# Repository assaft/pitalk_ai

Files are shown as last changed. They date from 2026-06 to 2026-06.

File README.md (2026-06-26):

# Introduction
This MD idescribes the creation of a device for recording, sending, receiving and playing vocal messages. 

## Device Goal
Enable easy voice messaging between kids. One click to start/end recording, one click to play an incoming. 

## Device Components
* Touch screen
* Microphone
* Speaker
* Amplifier
* System on chip - raspberry pi.
* Button with light
* PCB board, header cables, enclosure 

## Typical Use Case
Using the touch screen, user A can initiate a recording of a message to a particular pre-configured friend - user B. The microphone is used for the recording and a file is saved. Once user A presses to finish the recording, the file will be sent over the internet (using a Wifi connection), and reach the device of the recipient - user B. User B's device screen will show that there is an incoming message that hasn't been heard. Once user B presses on the screen to play it, the amplifier and speaker will be used to play it. 

# Requirements

## Functional Requirements
* A user can record a new message and send it to one of his/her friends. 
* A user can browse old messages he/she received and listen to them.
* A user can have a custom different list of friends - each user a different list 
* The list of friends per user should be editable.

## System Requirements
* The device should support reboot, shut down, turn on
* The device should have a Wifi access point mode so smartphones can connect to itto configure the Wifi network.

## Package Engineering Requirements
* The device should be packaged in a compact box
* The device should only have one external connection for power
* The screen, speaker, microphone and button should be front facing.
* The micro USB power should be side-facing.
* The comopnents should be mounted to the top or sides of the box, not to the bottom.
* The bottom should be openable using screws, giving access to all components inside.
* The raspberry pi should be attached on one of the sides to allow easy access to the screen, speaker, microphone and button.
* A custom PCB board should be used to simplify connectivity and maintenance
* The PCB should connect to the Raspberry Pi GPIO interface using a
  2×20 male pin header.

## PCB Board requirements
* The board should not include the amplifier - it should include a female socket for the amplifier to be connected to it using a male header that was soldered to it. 
* The board should not include the microphone because the microphone is attached to the front of the device. The microphone will have pin header soldered to it.
* there should be board connectors on the pcb for connecting it to the microphone, speaker, button and screen; the screen connector should be keyed/locking.

# Components

## Models
1. Controller: Raspberry Pi Zero 2W
2. Screen: Waveshare 2 inch Capacitive Touch Display Module (ST7789T3, CST816D)
3. Speaker: Gikfun 2 inch 4Ohm 3W Full Range Audio Speaker Stereo Woofer Loudspeaker
4. Amplifier: Max98357 I2S 3W Class D Amplifier
5. Microphone: INMP441 Omnidirectional Microphone attached over a Perfboard PCB of 2cm x 2cm
7. Button: momentary push button with led light

## Dimensions

| Component | Length | Width | Depth / Thickness | Notes |
|---|---|---|---|---|
| Raspberry Pi Zero 2W | 65 mm | 30 mm | ~5 mm | Board only; add ~2 mm for protruding micro-SD card |
| Waveshare 2" Capacitive Touch LCD (ST7789T3 / CST816D) | 58.8 mm | 37.1 mm | ~4 mm | PCB size; active display area is 40.8 × 30.6 mm |
| Gikfun 2" 4Ω 3W Speaker | 52.6 mm | 52.6 mm | 30 mm | Square frame |
| MAX98357 I2S Class-D Amplifier (breakout) | 19.4 mm | 17.8 mm | 3 mm | Adafruit-style breakout board |
| INMP441 Microphone (on 20 × 20 mm perfboard) | 20 mm | 20 mm | ~11 mm | Perfboard size per design spec; sensor itself is 4.7 × 3.8 × 1 mm |
| Momentary Push Button with LED | Ø 16–22 mm | — | ~39 mm | Circular; diameter depends on selected model (common: 16 mm or 22 mm panel cutout) |

# Box Arrangement

Two candidate front-face layouts. Scale: 1 char ≈ 5 mm.

## Layout 1 — Portrait (80 × 155 mm)

Screen on top, speaker in the middle, mic and button at the bottom.

```
╔══════════════════╗
║                  ║
║  ┌────────────┐  ║
║  │            │  ║
║  │   SCREEN   │  ║  58.8 × 37.1 mm
║  │            │  ║
║  └────────────┘  ║
║                  ║
║   ┌──────────┐   ║
║   │ ·  ·  ·  │   ║
║   │  ·  ·  · │   ║  52.6 × 52.6 mm
║   │ ·  ·  ·  │   ║
║   │  ·  ·  · │   ║
║   └──────────┘   ║
║                  ║
║   ◎         ◉    ║
║   mic       btn  ║
╚══════════════════╝
     80 × 155 mm
```

USB-C on the right side.

## Layout 4 — Landscape (150 × 80 mm)

Speaker on the left, screen on the right, mic and button below the screen.

```
╔══════════════════════════════════════╗
║                                      ║
║  ┌────────────┐  ┌────────────┐      ║
║  │ ·  ·  ·  · │  │            │      ║
║  │  ·  ·  ·   │  │   SCREEN   │      ║  58.8 × 37.1 mm
║  │ ·  ·  ·  · │  │            │      ║
║  │  ·  ·  ·   │  └────────────┘      ║
║  └────────────┘       ◎    ◉         ║
║                      mic   btn       ║
╚══════════════════════════════════════╝
  52.6 × 52.6 mm          150 × 80 mm
```

USB-C on the bottom edge (side of box). Button centered below screen, mic to its left.

## Internal Layout

### View from bottom

### View from the side

# PCB Design

Board: **76 mm × 58 mm**, four-layer, 1.6 mm FR4:

1. `F.Cu` — connector escapes and signals
2. `In1.Cu` — continuous ground plane
3. `In2.Cu` — secondary signal routing
4. `B.Cu` — signals and power

The authoritative wiring specification is [`pcb/pcb.md`](pcb/pcb.md). The
KiCad board is [`pcb/kicad/pitalk.kicad_pcb`](pcb/kicad/pitalk.kicad_pcb).
The matching schematic is
[`pcb/kicad/pitalk.kicad_sch`](pcb/kicad/pitalk.kicad_sch).

Regenerate it with:

```sh
.venv/bin/python pcb/kicad/build.py
.venv/bin/python pcb/kicad/build_schematic.py
```

## Connectors

| Ref | Footprint | Function |
|-----|---|---|
| J1 | 2×20 2.54 mm male pin header | Raspberry Pi Zero 2W GPIO |
| J2 | JST GH SM15B 1.25 mm 1×15 male side-entry header | Waveshare 2" touch display |
| J3 | 1×7 2.54 mm female socket | MAX98357A amplifier module |
| J4, J5 | 1×3 2.54 mm male headers | INMP441 microphone |
| J6 | 1×4 2.54 mm male header | Momentary button + LED |

## GPIO Assignments (Raspberry Pi Zero 2W)

| Pin | GPIO | Net | Description |
|-----|---|-----|---|
| 1, 17 | 3V3 | +3V3 | Power |
| 2, 4 | 5V | +5V | Power (amp) |
| 3 | GPIO2 | I2C_SDA | Touch screen SDA |
| 5 | GPIO3 | I2C_SCL | Touch screen SCL |
| 7 | GPIO4 | TOUCH_INT | Touch interrupt |
| 12 | GPIO18 | I2S_BCLK | I2S bit clock (amp + mic) |
| 13 | GPIO27 | DISP_RST | Display reset |
| 15 | GPIO22 | BTN_SW | Button input |
| 19 | GPIO10 | SPI_MOSI | Display data |
| 22 | GPIO25 | DISP_DC | Display data/command |
| 23 | GPIO11 | SPI_SCLK | Display clock |
| 24 | GPIO8 | SPI_CE0 | Display chip select |
| 32 | GPIO12 | DISP_BL | Backlight PWM |
| 33 | GPIO13 | GPIO13 | LED drive (→ R1 → BTN_LED) |
| 35 | GPIO19 | I2S_LRCLK | I2S LR clock (amp + mic) |
| 38 | GPIO20 | I2S_DIN | I2S data from mic → RPi |
| 40 | GPIO21 | I2S_DOUT | I2S data RPi → amp |

## Passives

| Ref | Value | Purpose |
|-----|---|---|
| R1 | 330 Ω 0402 | BTN_LED current limiter (GPIO13 → LED) |
| C1 | 100 nF 0402 | +3V3 decoupling |
| C2 | 100 nF 0402 | +5V decoupling |

# Software code

# Todos 
* ~~Adding the component dimensions - width, height, depth - see section above.~~
* ~~Creating the box arrangment for organizing the components in a box - see section above.~~
* ~~Create a PCB board to simplify connections and maintenance - see section above.~~
* Writing the software for implementing the service.

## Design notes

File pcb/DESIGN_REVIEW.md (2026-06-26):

# PiTalk PCB — Independent Verification Report

**Reviewer pass date:** 2026-06-27 (third pass — re-verification after the
fabrication-output regeneration, commit `b4b90ed`; second pass covered the
silkscreen-label update, commit `3b99e36`)
**Scope:** schematic, netlist, PCB, DRC/ERC, layout, datasheet pinouts,
connector silkscreen.
**Sources reviewed:** `pcb.md`, `kicad/pitalk.kicad_sch`, `kicad/pitalk.kicad_pcb`,
`kicad/pitalk.net.xml`, `kicad/erc.json`, `kicad/drc.json`, `kicad/build.py`,
`kicad/board-statistics.rpt`, `kicad/PRE_MANUFACTURING_VALIDATION.md`.

## What changed since the previous pass — and whether the verdict moves

The only board change since the first review (`720910e`) was **adding 20
assembly-facing pin labels to the front silkscreen** (`3b99e36`). I confirmed
this directly:

- **The schematic and netlist are byte-for-byte unchanged** (`git diff 720910e
  HEAD -- pitalk.kicad_sch pitalk.net.xml` is empty). Every electrical finding
  from the first pass therefore still holds without re-litigation — the
  I2S/backlight pin-conflict resolution, C1 polarity, no double-driven pins, and
  the NC list are all still correct.
- **The 20 new silkscreen labels are all correct** (§4 below).
- **The fabrication-output staleness (Finding #5) is now resolved** by commit
  `b4b90ed`. All of `kicad/fabrication/` plus `board-statistics.rpt`/`drc.json`
  were regenerated (dated 2026-06-27 01:26–01:27) from the current board, and
  re-verified this pass (§5 below).

**Net answer to "is the result any different than before?"** The electrical
verdict is unchanged (still sound). The board is now better documented for
assembly (correct pin labels) **and** the fabrication outputs are now current
and consistent with the source — Finding #5 is closed.

## Methodology

The intended netlist was reconstructed by hand from `pcb.md` and compared
node-by-node against the KiCad-exported netlist (`pitalk.net.xml`). Footprints,
the PCB stackup/zones/outline, and the automated ERC/DRC/parity reports were
then independently cross-checked. No KiCad, Python, or PCB design files were
modified during this review. Two documentation findings (#1, #3 below) were
corrected in `pcb.md`.

---

## 1. Electrical netlist — cross-checked against `pcb.md` ✅

Every signal net matches the spec. All 21 functional nets verified:

| Net | Pi pin(s) | Accessory | Verdict |
|---|---|---|---|
| SPI_MOSI/MISO/SCLK | 19/21/23 | J2 5/4/6 | ✅ |
| LCD_CS/DC/RST | 24/22/13 | J2 8/9/10 | ✅ |
| LCD_BL | 32 (BCM12) | J2 11 | ✅ remap from BCM18 honored |
| TP_SDA/SCL/INT/RST | 3/5/7/11 | J2 12/13/14/15 | ✅ |
| I2S_BCLK | 12 (BCM18) | J3 2 + J5 3 | ✅ shared amp+mic |
| I2S_LRCLK | 35 (BCM19) | J3 1 + J5 2 | ✅ shared amp+mic |
| AMP_DIN | 40 (DOUT) | J3 3 | ✅ |
| MIC_SD | 38 (DIN) | J4 1 | ✅ full-duplex I2S correct |
| BTN_SW / LED_A | 15 / 33→R1→J6 3 | J6 1 | ✅ 330 Ω in series |
| +3V3 | 1, 17 | J2 1, J4 2 | ✅ |
| +5V | 2 | J3 7, C1+ | ✅ |
| GND | 6,9,14,20,25,30,34,39 | all module grounds, C1− | ✅ |

- **I2S bus conflict avoidance is correct.** BCM18 is freed for the I2S bit
  clock and the backlight is genuinely moved to BCM12 (pin 32) in the netlist —
  the most error-prone part of this design is done right.
- **C1 polarity correct:** pin 1 (+) → +5V, pin 2 (−) → GND.
- **No double-driven pins / no shorts:** every pad appears in exactly one net.
- No-connects match spec: J2.2, J2.7 (module 3V3-out, SD_CS) and J3.4, J3.5
  (GAIN, SD) are NC.

## 2. Automated checks — independently confirmed ✅

- **ERC:** 0 violations. All global labels have a matching partner (each named
  net verified to have ≥2 nodes — no orphan/typo labels).
- **DRC:** 0 violations, 0 unconnected items, **0 schematic/PCB parity issues** —
  the board matches the schematic.
- Min clearance 0.385 mm, min track 0.25 mm, min drill 0.30 mm — all
  comfortably manufacturable.

## 3. Physical / layout — confirmed from the PCB file ✅

- **76 × 58 mm** outline confirmed (Edge.Cuts forms a clean closed rectangle
  0,0 → 76,58).
- **4-layer stack** `F.Cu / In1.Cu (power) / In2.Cu (signal) / B.Cu`, 1.6 mm.
- **In1.Cu is a single continuous GND pour** (one zone, filled, spanning the
  full board with thermal reliefs and mounting-hole keepouts) — no split planes.
  Signals route on F/In2/B (98/34/32 segments). Proper reference plane.
- 4× 3.2 mm NPTH mounting holes present.
- Footprints all match the spec: J2 = side-entry SMD JST GH SM15B; J3 =
  **female** PinSocket 1×07 (matches "socket" requirement); mic on two 1×03
  headers; pad/drill counts reconcile (61 THT + 17 SMD/J2 + 4 NPTH).
- **Outline/stackup/plane re-confirmed on the current file:** Edge.Cuts bbox is
  exactly 0,0 → 76,58; copper stack is `F.Cu / In1.Cu / In2.Cu / B.Cu`; the
  single zone is `(net "GND") (layer "In1.Cu")`. Routing was re-generated by
  `build.py` (now 86/34/32 segments on F/In2/B vs 98/34/32 before) but
  connectivity is intact — see §2 and Finding #5.

## 4. Connector silkscreen labels — independently verified ✅

The 20 new `F.SilkS` text items were extracted from the PCB and each was matched
to the nearest pad and that pad's net. **All 20 are correct in both name and
placement:**

| Connector | Labels (pin order) | Maps to net | Verdict |
|---|---|---|---|
| J4 mic (vertical 1×3) | SD / 3V3 / GND | MIC_SD / +3V3 / GND | ✅ y-aligned, text to the right |
| J5 mic (vertical 1×3) | GND / LRC / BCLK | GND / I2S_LRCLK / I2S_BCLK | ✅ y-aligned |
| J6 button (horizontal 1×4) | SW / GND / LED / GND | BTN_SW / GND / LED_A / GND | ✅ x-aligned, vertical text below |
| J3 amp socket (1×7) | LRC / BCLK / DIN / NC / NC / GND / 5V | I2S_LRCLK / I2S_BCLK / AMP_DIN / NC / NC / GND / +5V | ✅ y-aligned, text to the left |
| J1 Pi header | PIN1, "1=3V3 2=5V", "39=GND 40=DIN" | orientation + high-risk endpoints | ✅ ends labelled correctly |

- All labels are on **F.SilkS** (top/assembly side, where every connector lives)
  — correct, none mirrored onto the back.
- The labels sit clear of the board edge and clear of pads — consistent with
  **DRC reporting 0 silkscreen violations** (no silk-over-pad / silk-clipped).
- Minor cosmetic note only (no action required): J5.1's *module* function is
  `L/R` (the channel-select pin), but it is silkscreened **`GND`** because the
  board ties it to ground. That is electrically accurate; just be aware the
  module's own pin marking there reads `L/R`, not `GND`, when orienting the part.

## 5. Fabrication outputs — regenerated and re-verified ✅

After Finding #5 was raised, commit `b4b90ed` regenerated the full output set.
Independently confirmed against the current board:

- **All `kicad/fabrication/` files re-dated 2026-06-27 01:26**, plus
  `drc.json` (01:27) and `board-statistics.rpt` (01:27) — no longer stale.
- **In1.Cu GND plane is filled in the gerber** (`pitalk-In1_Cu.g1` contains a
  closed `G36…G37` copper region, ~92 kB). Even though the saved
  `.kicad_pcb` still caches the zone unfilled (`filled_polygon` = 0), KiCad
  fills zones on plot, so the *exported* plane is correct and complete — the
  load-bearing GND pour reaches the through-hole pads as required.
- **New silkscreen labels are in the gerber:** `pitalk-F_Silkscreen.gto` grew
  16 kB → 47 kB; `B_Silkscreen` remains ~empty, confirming all 20 labels are
  front-side only (not mirrored to the back).
- **Job/spec consistent:** `pitalk-job.gbrjob` is KiCad/Pcbnew, dated
  2026-06-27 01:26, 76.15 × 58.15 mm (board + plot margin), 4-layer, 1.6 mm,
  ENIG.
- **Counts reconcile with the design:** statistics report 76 × 58 mm, 61 THT +
  17 SMD + 4 NPTH pads; DRC re-run is clean (0 violations, 0 unconnected,
  0 parity).
- `pitalk.ipc` is now a full **IPC-2581 rev C** export (all layers + BOM/AVL),
  which is why it grew from ~7 kB to ~720 kB — a richer interchange format, not
  a defect.

**Residual (latent, low-risk):** the editable `.kicad_pcb` still saves the zone
unfilled because `build.py`/`kiutils` writes only the zone outline. The
committed gerbers are correct, but if anyone re-plots **from the GUI** they
should *Fill All Zones* (`B`) first; a `kicad-cli`/`build.py` re-export fills
automatically.

---

## Findings

**🟢 1 — RESOLVED — Doc/design mismatch on GND pins 20 & 30.**
The schematic ties **all 8** Pi ground pins (6, 9, 14, 20, 25, 30, 34, 39) to
GND, while `pcb.md` previously listed pins 20 and 30 as "not connected." The
schematic's choice is electrically *better* (more ground returns). **Fixed in
`pcb.md`:** pins 20 and 30 are now shown as GND rows in the full-wiring table,
removed from the "Unused header pins" list, and a note clarifies that all eight
Pi ground pins tie to the board GND plane. Design unchanged.

**🟢 2 — RESOLVED (module-confirmed) — Amplifier `GAIN`/`SD` defaults.**
J3.4 (GAIN) and J3.5 (SD) are left NC, relying on the breakout's onboard
resistors. The module's **back-side silkscreen** (now captured in
`images/max98357a-gain-sd-defaults.jpg` and documented in the Amplifier section)
explicitly states its as-shipped defaults: **"Default 9db Gain & (L+R)/2 out"**,
`MAX98357A I2S Mono Amp.`, `Vin: 2.5-5.5V`, `4-8Ω 3W`. This confirms the board
actively pulls `SD` to an *enabled* state in (L+R)/2 mono and leaves `GAIN`
floating for +9 dB — so leaving both pins unconnected on the carrier is correct
and the amp powers up enabled. **Residual check (assembly-time only):** confirm
the unit actually received is the pictured module and not a bare clone lacking
the `SD` pull; the 5 V VIN is within the printed 2.5–5.5 V range and the 4 Ω
speaker is within the printed 4–8 Ω range.

**🟢 3 — RESOLVED — Speaker wording inconsistency.**
The Speaker section previously said the speaker connects "via a 2-pin board
connector," contradicting the PCB Board section ("not a PCB connector"). The
schematic/PCB correctly have **no** speaker connector. **Fixed in `pcb.md`:** the
Speaker section now states the speaker wires directly to the amplifier module's
`OUT+`/`OUT-` terminals and is not a carrier-PCB connector. Design unchanged.

**🟢 4 — No action needed — No external I2C pull-ups / no 3V3 bulk cap.**
Acceptable: the Pi has fixed 1.8 kΩ pull-ups on BCM2/3, and the accessory
modules carry their own local decoupling. Noted for completeness.

**🟢 5 — RESOLVED — GND pour fill & stale fab outputs.**
*Raised on the second pass:* the silkscreen rebuild left the In1.Cu GND pour
saved **unfilled** and the committed `fabrication/` gerbers were **stale**
(Jun 24, pre-label). This mattered because the GND pour is **load-bearing** —
there are **zero GND stitching vias**, so through-hole GND pads depend on the
pour reaching them (plus 35 surface GND segments).

*Resolved by commit `b4b90ed`:* the entire output set was regenerated from the
current board and re-verified (§5 above) — the In1.Cu gerber carries a filled
copper region, `F_Silkscreen` now includes the 20 labels, and DRC/statistics
are current and clean. **Latent caveat retained:** the editable `.kicad_pcb`
still saves the zone unfilled, so a *GUI* re-plot needs *Fill All Zones* (`B`)
first; CLI/`build.py` exports fill automatically.

## Remaining manufacturing gates (cannot be closed from CAD)

Concur with `PRE_MANUFACTURING_VALIDATION.md`. Load-bearing items:

- **Mate/orientation of J1 (2×20) and J2 (15-pin JST GH) cables** — verify pin-1
  and that neither can seat reversed.
- **Physical fit** of the exact INMP441 and MAX98357A modules over a 1:1
  printout.
- **C1 voltage rating** ≥ 6.3 V (10 V preferred); confirm polarity at assembly.
- **Supply budget** for amplifier peaks (~650 mA) to avoid Pi undervoltage.
- **Fab DFM** — map to the chosen vendor's 1.6 mm 4-layer stack (no controlled
  impedance required).
- First-article **continuity / rail-short / functional** bring-up.

## Verdict

**The electrical design is sound and internally consistent — netlist, ERC, DRC,
and schematic↔PCB parity all pass independent verification, and the
I2S/backlight pin-conflict resolution (the trickiest part) is correct.** The
schematic and netlist are unchanged from the first pass, so that verdict carries
over directly. The new connector silkscreen (20 labels) is **fully correct** in
name, net, side, and placement, and improves assembly safety.

**Finding #5 (raised last pass) is now closed:** the fabrication outputs were
regenerated from the current board and independently re-verified — the In1.Cu
gerber carries a filled GND plane, the new silkscreen labels are in
`F_Silkscreen`, and DRC/statistics are current and clean. The only remaining
items are the physical mating/fit gates (cable orientation, module footprints,
C1 rating, supply budget, fab DFM, first-article bring-up) — none of which can
be closed from CAD files alone — and a latent reminder to *Fill All Zones*
before any **manual GUI** gerber re-plot. The design and its fabrication set are
suitable for prototype fabrication.

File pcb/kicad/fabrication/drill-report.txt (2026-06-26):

Drill report for pitalk.kicad_pcb
Created on 2026-06-27T01:26:01

Copper Layer Stackup:
    =============================================================
    L1 :  F.Cu                      front
    L2 :  In1.Cu                    in1
    L3 :  In2.Cu                    in2
    L4 :  B.Cu                      back

Drill file 'pitalk-PTH.drl' contains
    plated through holes:
    =============================================================
    T1  0.300mm  0.0118"  (14 holes))
    T2  0.800mm  0.0315"  (4 holes))
    T3  1.000mm  0.0394"  (57 holes))

    Total plated holes count 75

Drill file 'pitalk-NPTH.drl' contains
    unplated through holes:
    =============================================================
    T1  3.200mm  0.1260"  (4 holes))

    Total unplated holes count 4

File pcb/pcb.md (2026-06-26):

# PiTalk PCB — Pin Connections

This document defines the electrical pin mapping for the PiTalk carrier PCB,
designed from scratch around the **Raspberry Pi Zero 2W** 40-pin header.

Each accessory gets its own section with a pin-mapping table. Columns:

| Column | Meaning |
|---|---|
| `pi_pin` | Physical pin number on the Pi 40-pin header (1–40) |
| `pi_bcm` | Broadcom GPIO number (BCMxx), or the power rail name for power/ground pins |
| `accessory_pin` | Signal/function on the accessory side (e.g. `gnd`, `v3.3`, `clock`) |

> Buses are shared where the hardware requires it: SPI0 drives the display,
> I2C1 drives the touch controller, and the I2S/PCM bus is shared by the
> amplifier (output) and microphone (input).

---

## Raspberry Pi Zero 2W — 40-pin header reference

For convenience, the full header pinout this design draws from:

| pi_pin | pi_bcm | pi_pin | pi_bcm |
|---:|---|---:|---|
| 1  | 3V3 | 2  | 5V |
| 3  | BCM2 (SDA1)| 4  | 5V |
| 5  | BCM3 (SCL1)| 6  | GND |
| 7  | BCM4 | 8  | BCM14 (TXD) |
| 9  | GND | 10 | BCM15 (RXD) |
| 11 | BCM17 | 12 | BCM18 (PCM_CLK) |
| 13 | BCM27 | 14 | GND |
| 15 | BCM22 | 16 | BCM23 |
| 17 | 3V3 | 18 | BCM24 |
| 19 | BCM10 (MOSI)| 20 | GND |
| 21 | BCM9 (MISO)| 22 | BCM25 |
| 23 | BCM11 (SCLK)| 24 | BCM8 (CE0) |
| 25 | GND | 26 | BCM7 (CE1)  |
| 27 | BCM0 (ID_SD)| 28 | BCM1 (ID_SC)|
| 29 | BCM5 | 30 | GND |
| 31 | BCM6 | 32 | BCM12 |
| 33 | BCM13 | 34 | GND |
| 35 | BCM19 (PCM_FS)| 36 | BCM16 |
| 37 | BCM26 | 38 | BCM20 (PCM_DIN) |
| 39 | GND | 40 | BCM21 (PCM_DOUT)|

---

## Display — Waveshare 2" Capacitive Touch (ST7789T3 + CST816D)

Single module combining an SPI display (ST7789T3) and an I2C capacitive
touch controller (CST816D). Driven by SPI0 (display) and I2C1 (touch).
Pin mapping follows the "Working with Raspberry Pi" table on the
[Waveshare 2inch Capacitive Touch LCD wiki](https://www.waveshare.com/wiki/2inch_Capacitive_Touch_LCD).
The `accessory_pin_id` numbering follows the module's
[pinout diagram](https://www.waveshare.com/img/devkit/LCD/2inch-Capacitive-Touch-LCD/2inch-Capacitive-Touch-LCD-details-9.jpg)
(the 15-pin header).

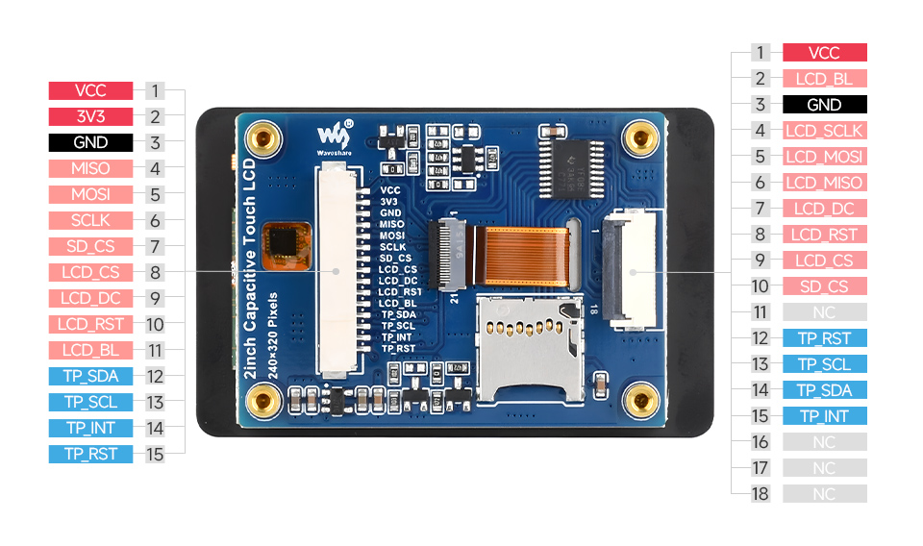
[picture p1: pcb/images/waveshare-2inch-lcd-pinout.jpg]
Waveshare 2" Capacitive Touch LCD pinout (15-pin header)


| pi_pin | pi_bcm | accessory_pin | accessory_pin_id |
|---:|---|---|---:|
| 17 | 3V3 | vcc (v3.3) | 1  |
| —  | — (not connected) | 3v3 (on-module regulator output) | 2  |
| 25 | GND | gnd | 3  |
| 21 | BCM9 (MISO)  | miso (spi miso) | 4  |
| 19 | BCM10 (MOSI) | mosi (spi data in) | 5  |
| 23 | BCM11 (SCLK) | sclk (spi clock) | 6  |
| —  | — (not connected) | sd_cs (on-module sd slot) | 7  |
| 24 | BCM8 (CE0) | lcd_cs (display chip select) | 8  |
| 22 | BCM25 | lcd_dc (data/command) | 9  |
| 13 | BCM27 | lcd_rst (display reset) | 10 |
| 32 | BCM12 | lcd_bl (backlight) — remapped from BCM18, see note | 11 |
| 3  | BCM2 (SDA1)  | tp_sda (touch i2c data) | 12 |
| 5  | BCM3 (SCL1)  | tp_scl (touch i2c clock) | 13 |
| 7  | BCM4 | tp_int (touch interrupt) | 14 |
| 11 | BCM17 | tp_rst (touch reset) | 15 |

Raspberry Pi 40-pin GPIO header showing display pins in red

> Accessory pins **2** (`3V3`, the on-module regulator output) and **7**
> (`SD_CS`, the micro-SD slot's chip select) are left unconnected on this board
> — both shown mapping to nothing above.
>
> 🔧 **Backlight remapped:** the Waveshare default wires `LCD_BL` to **BCM18**,
> which is also `PCM_CLK` (I2S BCLK) used by the amplifier and microphone below.
> Since BCM18 cannot serve both, `LCD_BL` is remapped on this board to
> **BCM12 (pin 32)** — a hardware-PWM-capable pin — freeing BCM18 for I2S.
> This requires routing `LCD_BL` to pin 32 on the PCB (not pin 12) and setting
> the backlight GPIO to BCM12 in software.

### PCB Connector

JST GH SM15B-GHS-TB 1.25 mm 15-pin male side-entry PCB header

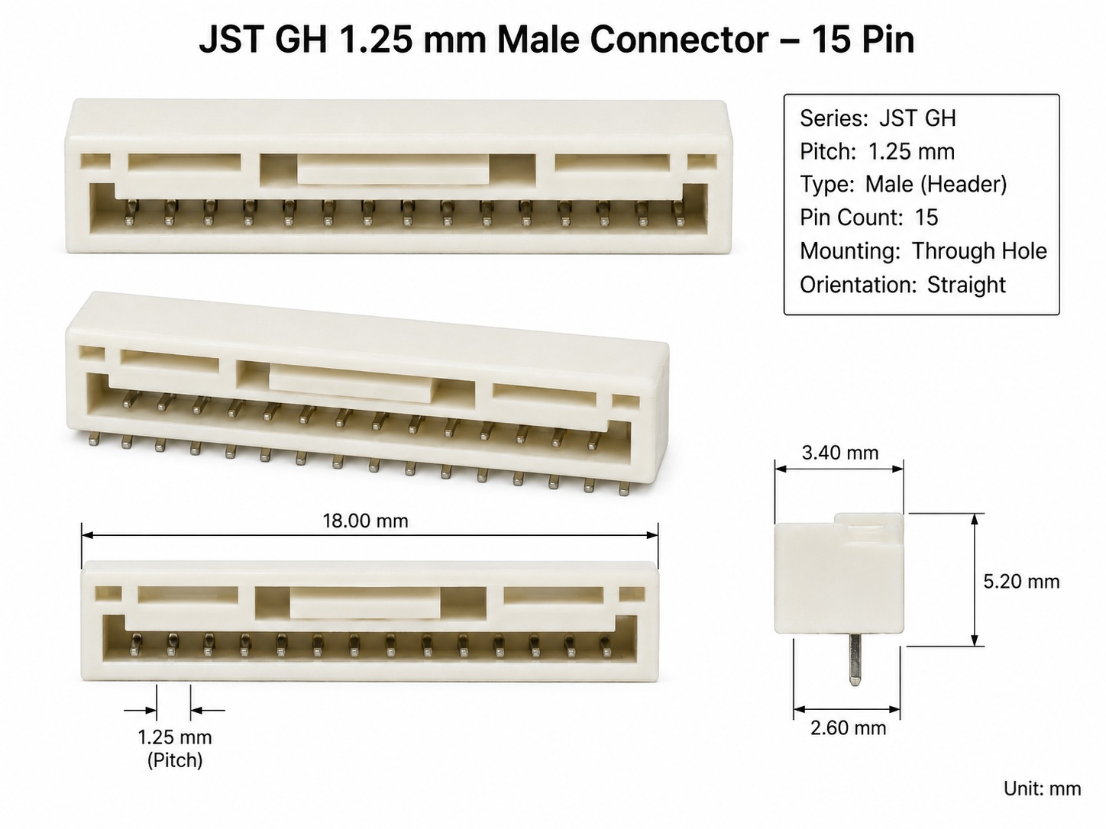
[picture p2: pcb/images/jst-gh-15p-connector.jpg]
JST GH1.25 15-pin connector (shown on the Waveshare module)


✅ **Verified**

---

## Amplifier — MAX98357A I2S Class-D (3W)

Receives audio from the Pi over the I2S/PCM bus. Mounted on the PCB via a
female socket (per board requirements). Speaker connects to its output.

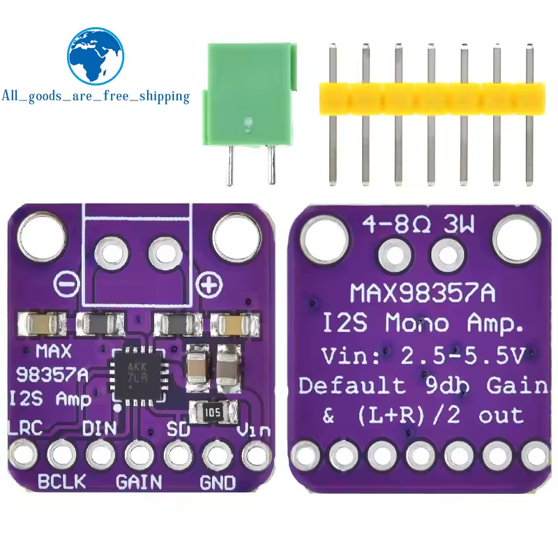
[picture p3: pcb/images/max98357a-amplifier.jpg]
MAX98357A I2S Class-D mono amplifier module


The `accessory_pin_id` numbering follows the module's 1×7 header order
(`LRC`, `BCLK`, `DIN`, `GAIN`, `SD`, `GND`, `VIN`).

| pi_pin | pi_bcm | accessory_pin | accessory_pin_id |
|---:|---|---|---:|
| 35 | BCM19 (PCM_FS)  | lrc (lr / word clock) | 1 |
| 12 | BCM18 (PCM_CLK) | bclk (bit clock) | 2 |
| 40 | BCM21 (PCM_DOUT)| din (i2s data in) | 3 |
| —  | — (not connected) | gain (gain select) | 4 |
| —  | — (not connected) | sd (shutdown / channel select) | 5 |
| 6  | GND | gnd | 6 |
| 2  | 5V | vin (5v) | 7 |

Raspberry Pi 40-pin GPIO header showing amplifier pins in red

The module's back-side silkscreen documents its onboard defaults:

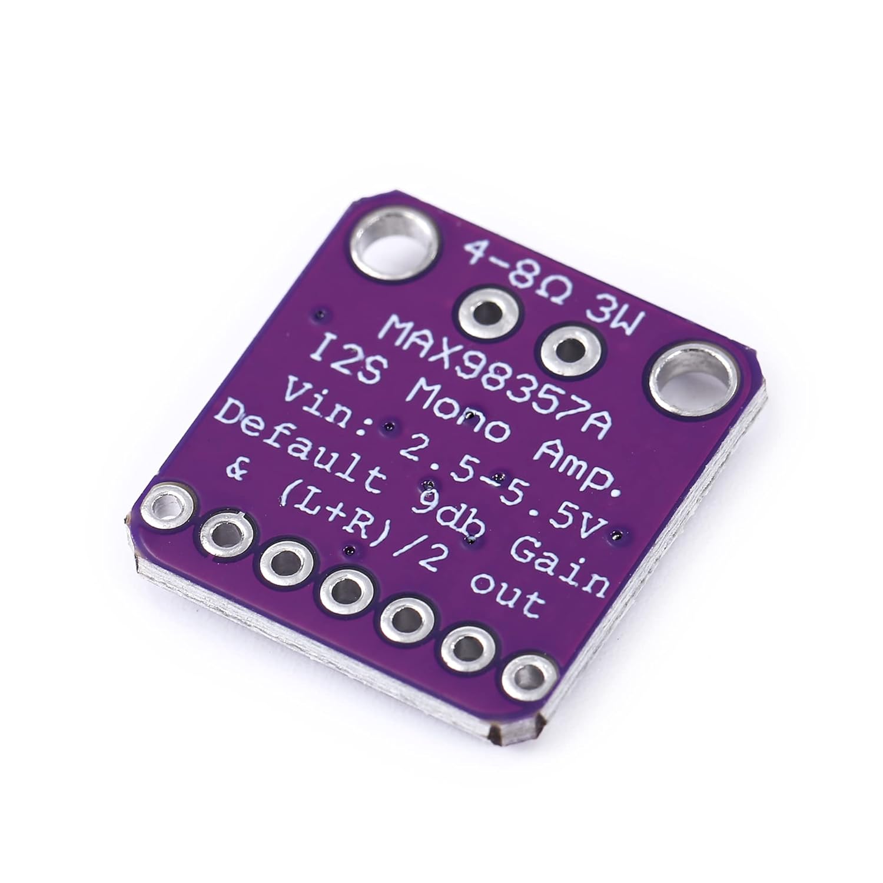
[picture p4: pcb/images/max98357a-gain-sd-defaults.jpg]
MAX98357A module back silkscreen showing gain and output defaults


> ```
> 4-8Ω 3W
> MAX98357A
> I2S Mono Amp.
> Vin: 2.5-5.5V
> Default 9db Gain
> & (L+R)/2 out
> ```

> Accessory pins **4** (`GAIN`) and **5** (`SD`, shutdown/channel-select) are
> set by the module's onboard resistors (not driven by the Pi) — both shown
> mapping to nothing above, and both left unconnected on this carrier.
>
> The module's silkscreen confirms its as-shipped defaults with these pins
> unconnected:
> - **`GAIN` left floating → +9 dB gain.**
> - **`SD` held by the onboard pull at the level that both enables the amplifier
>   and selects `(L+R)/2` stereo-averaged mono output.** Because the breakout
>   actively pulls `SD` to an enabled state, leaving it unconnected does **not**
>   shut the amplifier down — the chip powers up enabled in mono.
>
> This is why pins 4 and 5 are safe to leave unconnected on the PCB: the
> purchased module already sets them. (Verify the actual board carries these
> pulls — bare MAX98357A clones without the `SD` pull would otherwise stay in
> shutdown.)

### PCB Connector

2.54mm 7pin socket

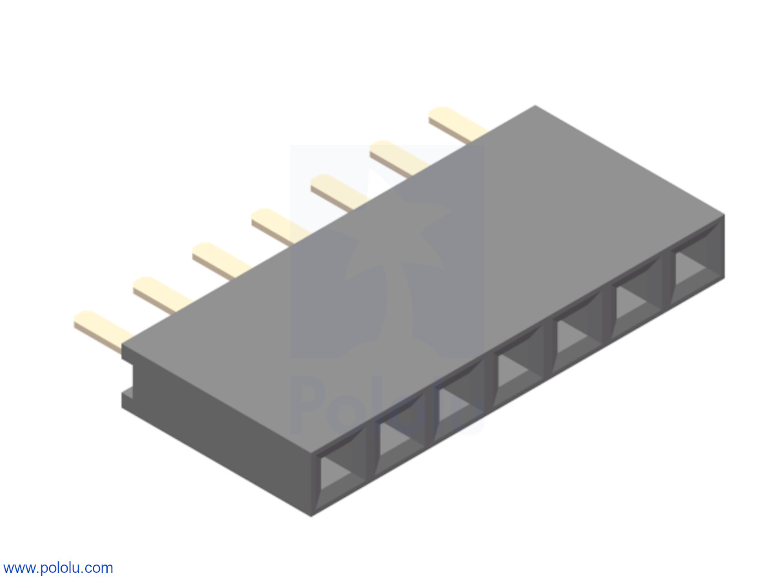
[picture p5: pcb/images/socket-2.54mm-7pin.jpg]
2.54 mm 1×7 female header socket


✅ **Verified**

---

## Microphone — INMP441 I2S MEMS

Sends audio to the Pi over the same I2S/PCM bus (shares BCLK and LRCLK with
the amplifier; uses the PCM data-in line). Connects via a board header.

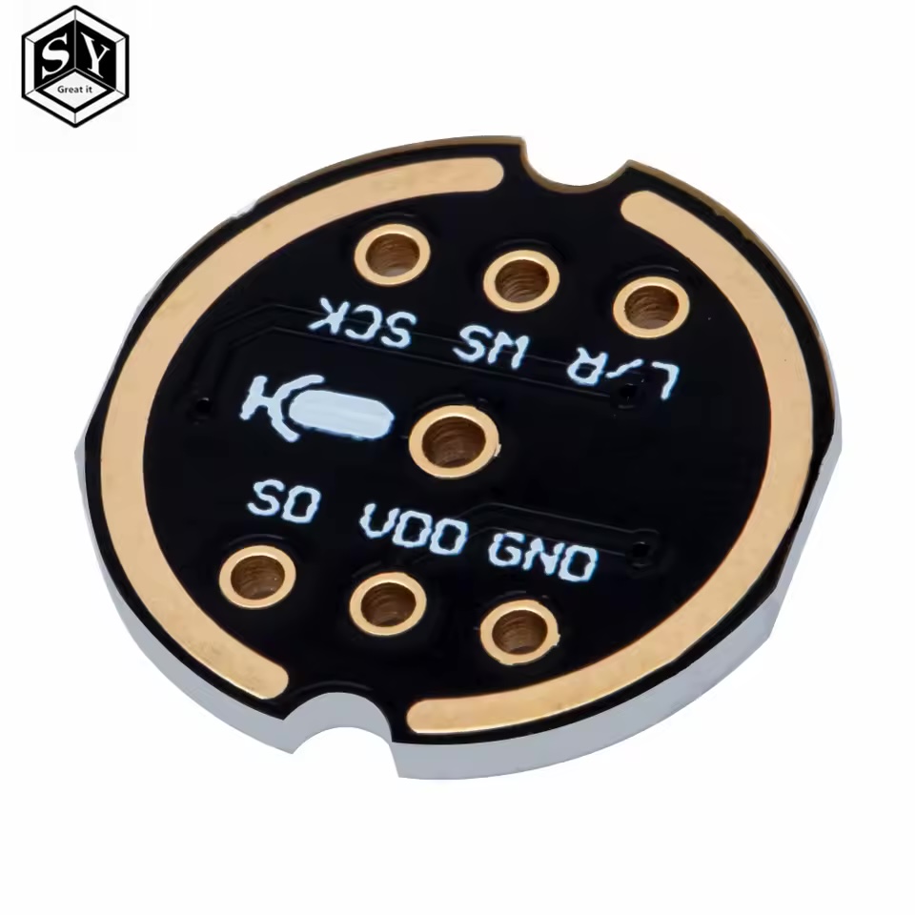
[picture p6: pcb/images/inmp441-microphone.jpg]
INMP441 I2S MEMS microphone module


The `accessory_pin_id` numbering follows the module's two 3-pin headers,
left-to-right: header 1 is `SD`, `VDD`, `GND`; header 2 is `L/R`, `WS`, `SCK`.

| pi_pin | pi_bcm | accessory_pin | accessory_pin_id |
|---:|---|---|---:|
| 38 | BCM20 (PCM_DIN)| sd (i2s data out) | 1 |
| 1  | 3V3 | vdd (v3.3) | 2 |
| 9  | GND | gnd | 3 |
| 14 | GND | l/r (channel select → gnd = left) | 4 |
| 35 | BCM19 (PCM_FS) | ws (word select) | 5 |
| 12 | BCM18 (PCM_CLK)| sck (bit clock) | 6 |

Raspberry Pi 40-pin GPIO header showing microphone pins in red

> Accessory pin **4** (`L/R`) is a static channel-select input, not a signal
> the Pi drives — tying it to `gnd` selects the left channel. Here it is wired
> to the Pi's **GND on pin 14** (a dedicated ground pin, separate from the mic's
> own `gnd` on pin 9). The mic module solders onto the headers straight through,
> unmodified — do **not** short `L/R` to `gnd` on the module; the tie is made
> through the header to the Pi ground pin.

### PCB Connector

2.54mm 1×3 male pin header (×2)

Two 2.54mm 1×3 male pin headers. The six accessory pins are split across the
two headers in `accessory_pin_id` order — pins 1–3 on the first header, pins
4–6 on the second. Pin order below is left-to-right, matching the module.

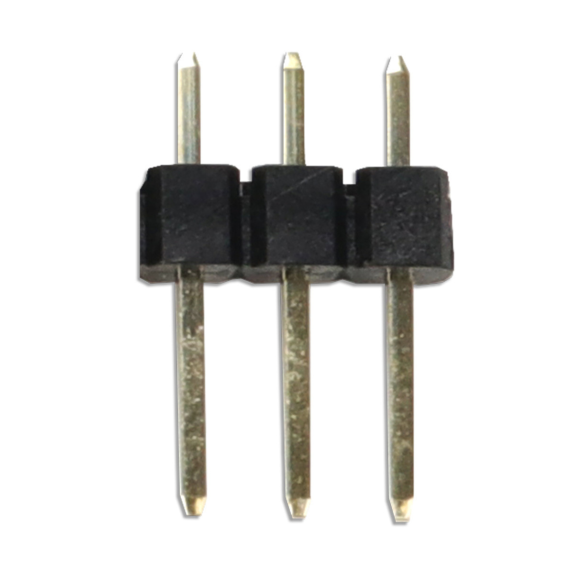
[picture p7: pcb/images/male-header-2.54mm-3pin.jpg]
2.54 mm 1×3 male pin header


```
Header A (1×3 male)          Header B (1×3 male)
┌───┬───┬───┐                ┌───┬───┬───┐
│ ▯ │ ▯ │ ▯ │                │ ▯ │ ▯ │ ▯ │
└───┴───┴───┘                └───┴───┴───┘
  1   2   3                    4   5   6
 sd  vdd gnd                 l/r  ws  sck
```

| header | pins (left-to-right) | accessory_pin_id |
|---|---|---|
| A | sd, vdd, gnd  | 1, 2, 3 |
| B | l/r, ws, sck  | 4, 5, 6 |

✅ **Verified**

---

## Speaker — Gikfun 2" 4Ω 3W

The speaker does **not** connect to the Pi header, and it is **not** a carrier
PCB connector. It wires directly to the amplifier module's bridge-tied output
terminals (`OUT+`/`OUT-`) on the MAX98357A board itself.

| amp_pin | accessory_pin |
|---|---|
| out+ | speaker + |
| out- | speaker - |

✅ **Verified**

---

## Button — Momentary push button with LED

Switch contact reads as a GPIO input; the LED is driven through an on-board
series current-limiting resistor.

| pi_pin | pi_bcm | accessory_pin |
|---:|---|---|
| 15 | BCM22 | sw (switch input) |
| 34 | GND | sw_gnd (switch return) |
| 33 | BCM13 | led+ (via series resistor) |
| 39 | GND | led- (led cathode) |

Raspberry Pi 40-pin GPIO header showing button pins in red

### PCB Connector

2.54mm 1×4 male pin header

A single 2.54mm 1×4 male pin header carries all four button signals,
left-to-right: `sw`, `sw_gnd`, `led+`, `led-`.

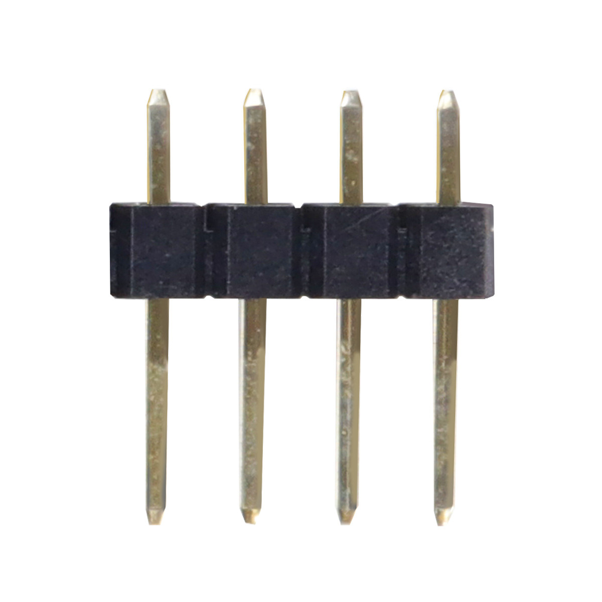
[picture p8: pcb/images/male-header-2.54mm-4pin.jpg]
2.54 mm 1×4 male pin header


```
1×4 male header
┌────┬────────┬──────┬──────┐
│ ▯  │   ▯    │  ▯   │  ▯   │
└────┴────────┴──────┴──────┘
  1       2       3      4
  sw    sw_gnd   led+   led-
```

---

## Full wiring

Consolidated view of every Raspberry Pi pin and which accessory pin it
connects to. `—` means that accessory does not use the pin. Power and ground
rails span several physical header pins; the per-component sections above list
the specific pins used.

Rows are one physical pin each. Where an accessory shares a rail (3V3, GND),
a separate header pin is allocated per accessory so every connection maps to a
single pin. (BCM18/BCM19 are genuine shared signal nets and stay on one pin.)
In addition to the per-accessory GND pins, **all remaining Pi ground pins
(20 and 30) are also tied to the board GND plane** — they carry no accessory
signal but provide extra ground returns. They appear below as GND rows with
`—` in every accessory column.

Raspberry Pi 40-pin GPIO header colored by connected component, with shared pins split between colors

| pi_pin | pi_bcm | display | amplifier | microphone | button |
|---:|---|---|---|---|---|
| 1  | 3V3 | — | — | vdd  | — |
| 2  | 5V | — | vin  | — | — |
| 3  | BCM2 (SDA1) | tp_sda | — | — | — |
| 5  | BCM3 (SCL1) | tp_scl | — | — | — |
| 6  | GND | — | gnd  | — | — |
| 7  | BCM4 | tp_int | — | — | — |
| 9  | GND | — | — | gnd  | — |
| 11 | BCM17 | tp_rst | — | — | — |
| 12 | BCM18 (PCM_CLK) | — | bclk | sck  | — |
| 13 | BCM27 | lcd_rst  | — | — | — |
| 14 | GND | — | — | l/r  | — |
| 15 | BCM22 | — | — | — | sw |
| 17 | 3V3 | vcc | — | — | — |
| 19 | BCM10 (MOSI) | mosi | — | — | — |
| 20 | GND | — | — | — | — |
| 21 | BCM9 (MISO) | miso | — | — | — |
| 22 | BCM25 | lcd_dc | — | — | — |
| 23 | BCM11 (SCLK) | sclk | — | — | — |
| 24 | BCM8 (CE0) | lcd_cs | — | — | — |
| 25 | GND | gnd | — | — | — |
| 30 | GND | — | — | — | — |
| 32 | BCM12 | lcd_bl | — | — | — |
| 33 | BCM13 | — | — | — | led+ |
| 34 | GND | — | — | — | sw_gnd |
| 35 | BCM19 (PCM_FS)  | — | lrc  | ws | — |
| 38 | BCM20 (PCM_DIN) | — | — | sd | — |
| 39 | GND | — | — | — | led- |
| 40 | BCM21 (PCM_DOUT)| — | din  | — | — |

> **Unused header pins** (not connected on this board):
> 4 (5V), 8 (BCM14/TXD), 10 (BCM15/RXD), 16 (BCM23), 18 (BCM24),
> 26 (BCM7/CE1), 27 (BCM0/ID_SD), 28 (BCM1/ID_SC), 29 (BCM5),
> 31 (BCM6), 36 (BCM16), 37 (BCM26).
>
> All eight Pi ground pins (6, 9, 14, 20, 25, 30, 34, 39) are tied to the
> board GND plane.

✅ **Verified**

---

## PCB Board

The carrier PCB must provide the following connectors, one per interface
(detailed in each accessory section above):

| # | Interface | Connector | Pins |
|--:|---|---|-----:|
| 1 | Raspberry Pi Zero 2W | 2×20 2.54 mm male pin header | 40 |
| 2 | Display (Waveshare 2" Touch) | JST GH SM15B 1.25 mm 1×15 male side-entry header | 15 |
| 3 | Amplifier (MAX98357A) | 2.54mm 1×7 female socket | 7 |
| 4 | Microphone (INMP441) | 2.54mm 1×3 male pin header (×2) | 3 + 3 |
| 5 | Button (push button + LED) | 2.54mm 1×4 male pin header | 4 |

> The speaker is **not** a PCB connector — it wires directly to the
> amplifier's output (see the Speaker section), not to the carrier board.

### Four-layer implementation

The KiCad implementation is a **76 mm × 58 mm**, 1.6 mm four-layer board:

| Layer | Use |
|---|-----|
| `F.Cu` | Connector escapes and primary signals |
| `In1.Cu` | Continuous GND plane |
| `In2.Cu` | Secondary signal routing |
| `B.Cu` | Remaining signals and power |

The microphone headers are placed on the opposite side of the board from the
amplifier socket. The amplifier socket and 5 V bulk capacitor are grouped
together. Four 3.2 mm mounting holes are provided.

KiCad board: [`kicad/pitalk.kicad_pcb`](kicad/pitalk.kicad_pcb)

KiCad schematic: [`kicad/pitalk.kicad_sch`](kicad/pitalk.kicad_sch)

Validation reports:

- [`kicad/erc.json`](kicad/erc.json) — schematic ERC
- [`kicad/drc-with-parity.json`](kicad/drc-with-parity.json) — PCB DRC and
  schematic/PCB parity
- [`kicad/PRE_MANUFACTURING_VALIDATION.md`](kicad/PRE_MANUFACTURING_VALIDATION.md)
  — datasheet, Gerber, power, layout, and remaining physical validation gates

The project ignores KiCad's `lib_footprint_mismatch` metadata warning because
the board is generated by `kiutils`. Pad counts, numbers, positions, sizes, and
drills were compared against the installed KiCad footprints and match exactly.

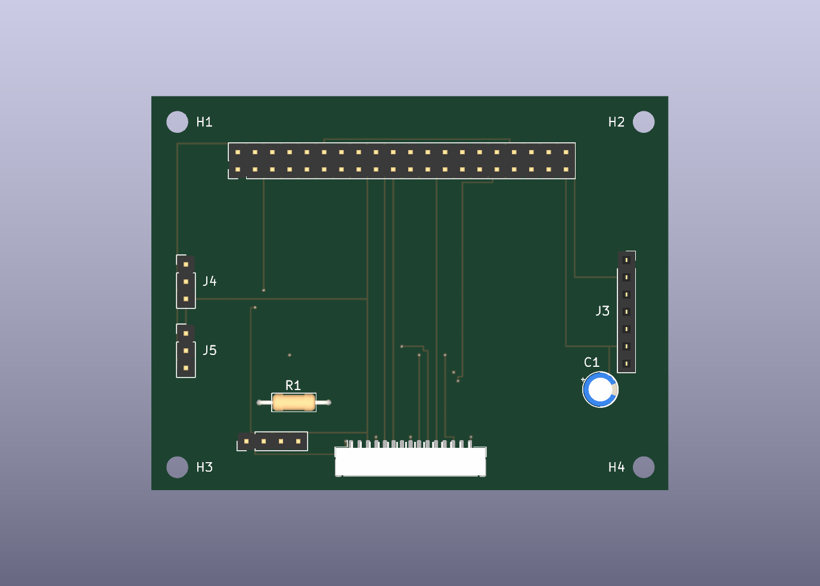
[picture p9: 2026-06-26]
pcb/kicad/preview/board-3d.png

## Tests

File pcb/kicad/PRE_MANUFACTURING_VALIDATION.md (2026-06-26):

# PiTalk PCB — Pre-Manufacturing Validation

Date: 2026-06-24

## Release status

**Conditional — suitable for prototype fabrication after the mechanical and
cable checks listed under “Remaining gates.”**

The electrical design and generated fabrication data pass the automated and
document-based checks that can be performed without physical parts or a
selected PCB manufacturer.

## Automated KiCad checks

| Check | Result |
|---|---|
| Schematic ERC | PASS — 0 violations |
| PCB DRC | PASS — 0 violations |
| Unconnected PCB items | PASS — 0 |
| Schematic/PCB parity | PASS — 0 issues |
| Gerber export | PASS |
| PTH/NPTH drill export | PASS |
| Footprint pad geometry vs installed KiCad libraries | PASS |

Reports:

- [`erc.json`](erc.json)
- [`drc-with-parity.json`](drc-with-parity.json)
- [`board-statistics.rpt`](board-statistics.rpt)

## Datasheet and pinout audit

### Raspberry Pi GPIO

The physical GPIO pin assignments match the standard Raspberry Pi 40-pin
header: SPI0, I2C1, PCM/I2S, power, and ground are mapped to the expected
physical pins.

Source:
[Raspberry Pi GPIO documentation](https://pip.raspberrypi.com/categories/685-whitepapers-app-notes/documents/RP-003613-WP/Using-gpio-pins.pdf)

### Waveshare 2-inch display

SPI, touch I2C, reset, interrupt, power, and ground match Waveshare's Raspberry
Pi table. `LCD_BL` is intentionally moved from BCM18 to BCM12 because BCM18 is
used as the I2S bit clock. Software must configure the display backlight as
BCM12.

J2 uses the male JST GH `SM15B-GHS-TB` side-entry footprint.

Source:
[Waveshare 2inch Capacitive Touch LCD](https://www.waveshare.com/wiki/2inch_Capacitive_Touch_LCD)

### MAX98357A amplifier module

The documented module photo confirms the seven-pin order:
`LRC, BCLK, DIN, GAIN, SD, GND, VIN`.

The 5 V supply is within the MAX98357A 2.5–5.5 V range. A 4 Ω speaker is
supported. The amplifier can draw approximately 650 mA at high output;
Adafruit recommends allowing at least 800 mA supply capacity for the amplifier.

C1 provides 10 µF bulk bypass capacitance near J3. The MAX98357A datasheet
specifies a 10 µF bypass capacitor and recommends additional bulk capacitance
for long supply paths. The selected breakout module also contains local
decoupling.

Sources:

- [MAX98357A datasheet](https://www.analog.com/media/en/technical-documentation/data-sheets/max98357a-max98357b.pdf)
- [Adafruit MAX98357A pinout and power guidance](https://learn.adafruit.com/adafruit-max98357-i2s-class-d-mono-amp/pinouts)

### INMP441 microphone module

The two three-pin headers match the module silkscreen:
`SD, VDD, GND` and `L/R, WS, SCK`. VDD is 3.3 V, and L/R is tied to ground to
select the left channel. BCLK and LRCLK are shared with the amplifier, while
the microphone uses the Pi PCM data-input net.

Only the pictured module/header arrangement is validated. INMP441 breakout
boards from different sellers are not mechanically standardized.

### Button and LED

The switch returns to ground and requires the Pi GPIO's internal pull-up to be
enabled in software. The LED is driven through 330 Ω. With a typical LED
forward voltage, GPIO current is approximately 3–5 mA, comfortably below the
Pi GPIO limit.

## Layout, power, and signal review

- Four-layer stack: `F.Cu / GND / signal / B.Cu`.
- In1 is a continuous ground plane with no routed signal splits.
- SPI clock and I2S bit clock are routed on F.Cu adjacent to the ground plane.
- The microphone connectors are separated from the amplifier connector.
- The amplifier bulk capacitor is close to the amplifier's 5 V input.
- Minimum track width: 0.25 mm.
- Power-track width: 0.40 mm.
- Minimum measured copper clearance: 0.31 mm.
- Through-vias: 0.60 mm diameter with 0.30 mm drills.
- Mounting holes: four 3.20 mm NPTH holes.
- Conservative resistance estimate for the entire 92 mm, 0.40 mm-wide 5 V
  copper network at 1 oz is about 0.11 Ω. At 650 mA this is about 72 mV drop;
  the actual Pi-to-amplifier path is shorter than the total network.

These dimensions are within common four-layer PCB capabilities.

## Gerber and drill inspection

Visual inspection files are in [`inspection/`](inspection/).

- F.Cu: PASS
- In1.Cu ground plane: PASS, continuous
- In2.Cu: PASS
- B.Cu: PASS
- PTH drill map: PASS
- NPTH drill map: PASS
- Board outline and four mounting holes: PASS

Fabrication files are in [`fabrication/`](fabrication/).

## Remaining gates

These cannot be closed from CAD files alone:

1. **J1 mating system:** confirm the exact female cable/socket that mates with
   the unshrouded 2×20 male header. Verify pin 1 at both ends and ensure the
   connector cannot be installed reversed.
2. **J2 cable assembly:** confirm a 15-position female-to-female JST GH cable
   and verify whether the harness is pin-for-pin or reversed when viewed from
   the mating faces.
3. **Microphone fit:** measure the actual center-to-center spacing and pin
   orientation of the purchased INMP441 module or its 20×20 mm carrier.
4. **Amplifier fit:** place the exact purchased module over a 1:1 print and
   verify body, speaker-terminal, and capacitor clearance.
5. **Component specification:** C1 must be rated at least 6.3 V; 10 V is
   preferred. Confirm polarity during assembly.
6. **Power budget:** the complete device power supply must cover the Pi,
   display, amplifier peaks, microphone, and margin. A weak Pi supply can cause
   undervoltage during loud audio.
7. **Manufacturer DFM:** select the fabricator and map this design to its stock
   1.6 mm four-layer stack-up. No controlled impedance is required, so the
   dielectric dimensions may be adapted to the manufacturer's standard stack.
8. **Physical prototype tests:** continuity, rail shorts, idle current, display
   SPI, touch I2C, microphone capture, amplifier playback, button, LED, and
   noise testing remain mandatory on the first assembled boards.

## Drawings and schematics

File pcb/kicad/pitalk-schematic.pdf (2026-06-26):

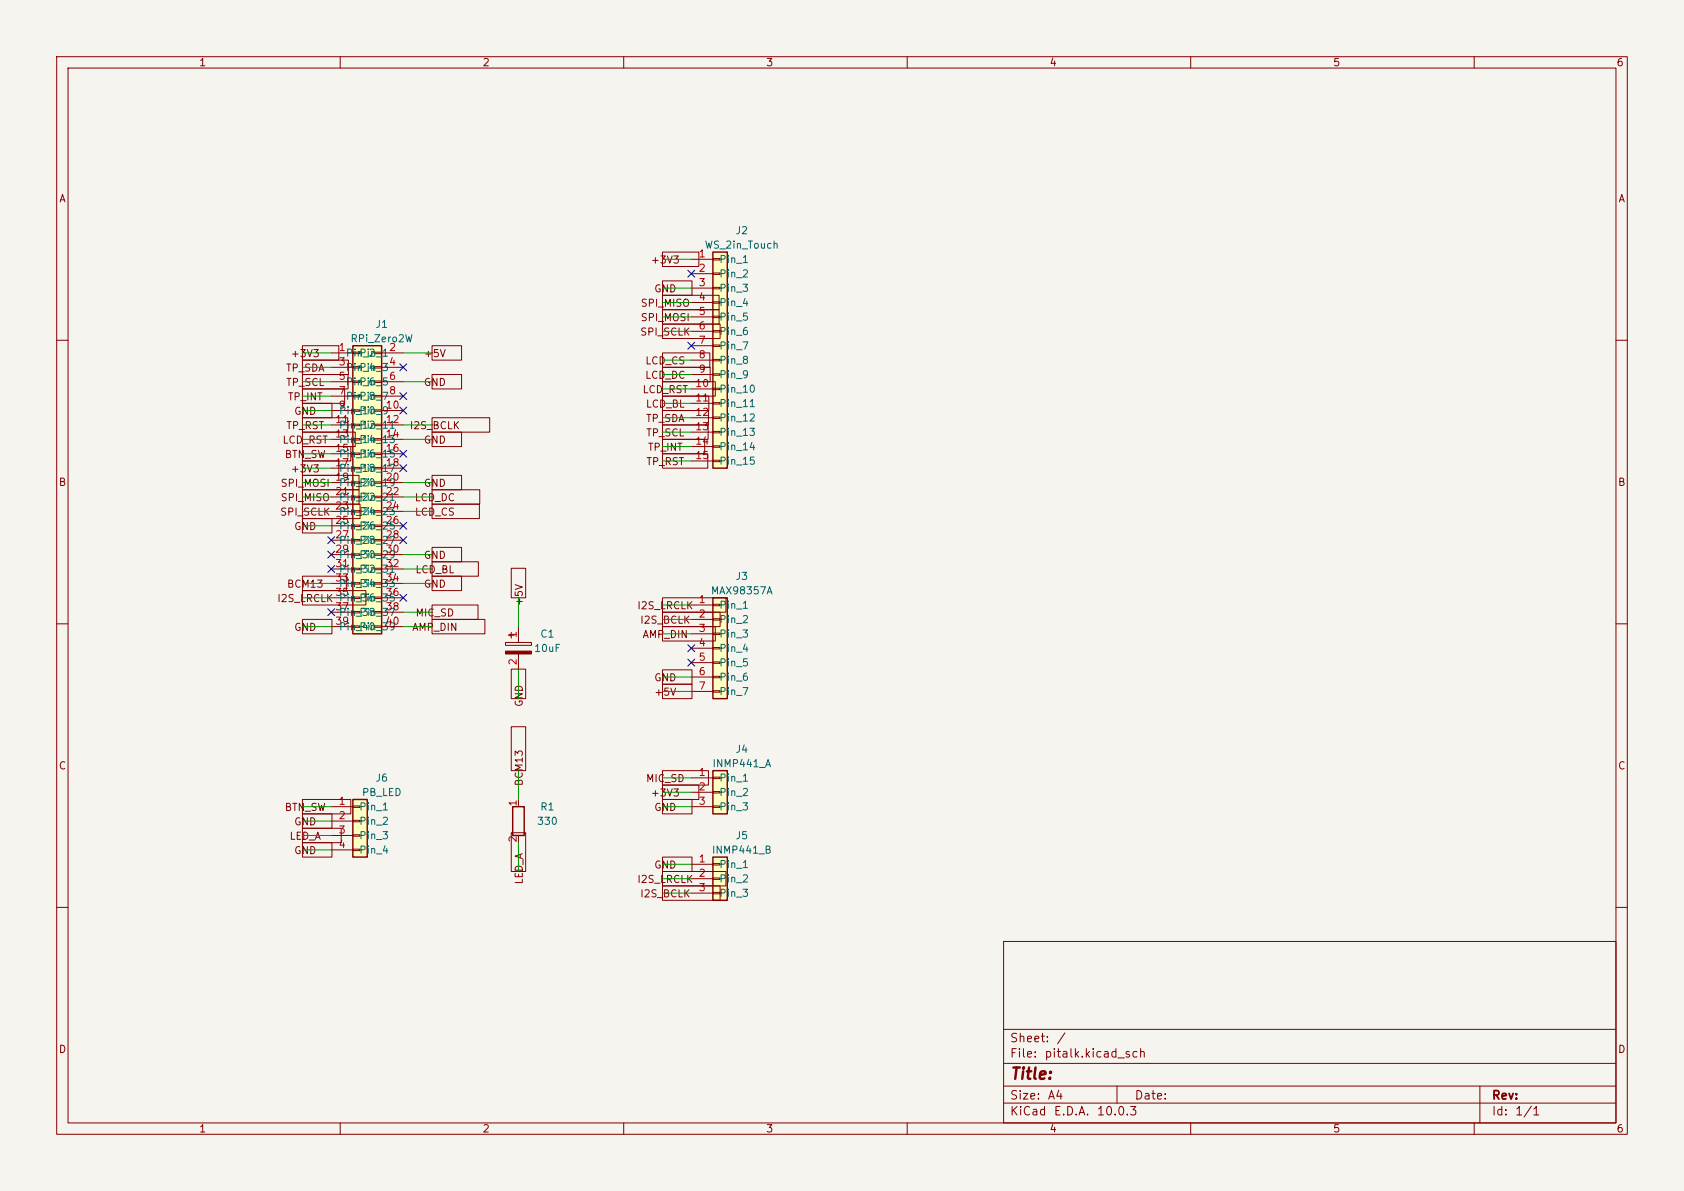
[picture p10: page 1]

Size: A4 | Rev:
KiCad E.D.A. 10.0.3 | Id: 1/1

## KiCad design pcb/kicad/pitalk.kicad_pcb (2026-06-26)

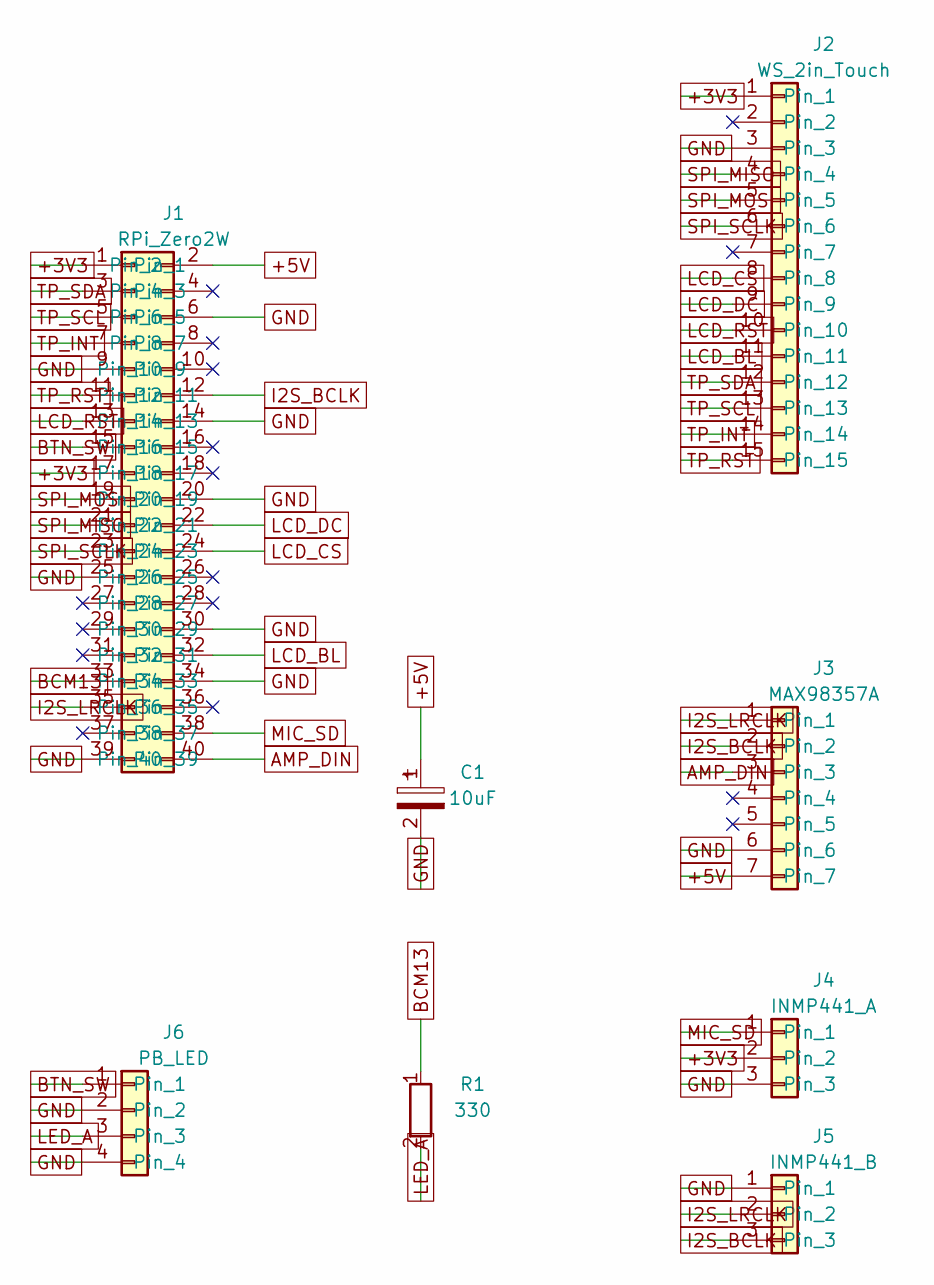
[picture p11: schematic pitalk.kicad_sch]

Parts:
C1: 10uF; CP_Radial_D5.0mm_P2.50mm
J1: RPi_Zero2W; PinHeader_2x20_P2.54mm_Vertical
J2: WS_2in_Touch; JST_GH_SM15B-GHS-TB_1x15-1MP_P1.25mm_Horizontal
J3: MAX98357A; PinSocket_1x07_P2.54mm_Vertical
J4: INMP441_A; PinHeader_1x03_P2.54mm_Vertical
J5: INMP441_B; PinHeader_1x03_P2.54mm_Vertical
J6: PB_LED; PinHeader_1x04_P2.54mm_Vertical
R1: 330; R_Axial_DIN0207_L6.3mm_D2.5mm_P10.16mm_Horizontal

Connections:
+3V3: J1.1, J1.17, J2.1, J4.2
+5V: C1.1, J1.2, J3.7
AMP_DIN: J1.40, J3.3
BCM13: J1.33, R1.1
BTN_SW: J1.15, J6.1
GND: C1.2, J1.6, J1.9, J1.14, J1.20, J1.25, J1.30, J1.34, J1.39, J2.3, J3.6, J4.3, J5.1, J6.2, J6.4
I2S_BCLK: J1.12, J3.2, J5.3
I2S_LRCLK: J1.35, J3.1, J5.2
LCD_BL: J1.32, J2.11
LCD_CS: J1.24, J2.8
LCD_DC: J1.22, J2.9
LCD_RST: J1.13, J2.10
LED_A: J6.3, R1.2
MIC_SD: J1.38, J4.1
SPI_MISO: J1.21, J2.4
SPI_MOSI: J1.19, J2.5
SPI_SCLK: J1.23, J2.6
TP_INT: J1.7, J2.14
TP_RST: J1.11, J2.15
TP_SCL: J1.5, J2.13
TP_SDA: J1.3, J2.12

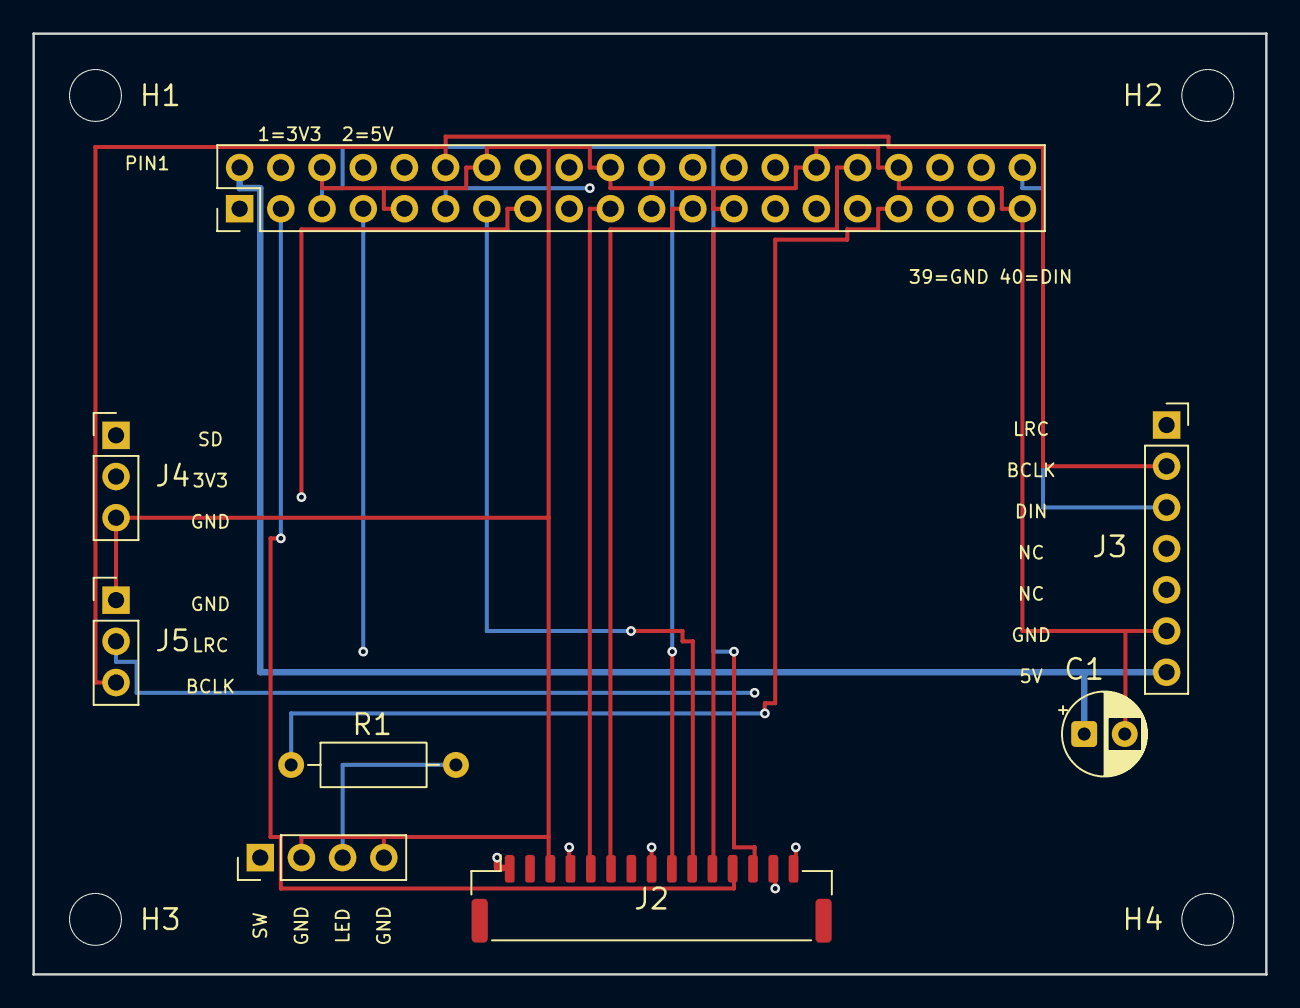
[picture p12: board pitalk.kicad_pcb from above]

Board: 4 copper layers, 76.0 x 58.0 mm, 12 parts (0 on the bottom side), 21 nets.

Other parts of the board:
H1, H2, H3, H4: M3; MountingHole_3.2mm_M3

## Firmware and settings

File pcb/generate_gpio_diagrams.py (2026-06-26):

from pathlib import Path


OUTPUT_DIR = Path(__file__).parent / "images"

COMPONENTS = {
    "display": {3, 5, 7, 11, 13, 17, 19, 21, 22, 23, 24, 25, 32},
    "amplifier": {2, 6, 12, 35, 40},
    "microphone": {1, 9, 12, 14, 35, 38},
    "button": {15, 33, 34, 39},
}

COLORS = {
    "display": "#1976d2",
    "amplifier": "#d7191c",
    "microphone": "#1b8f3a",
    "button": "#f28c00",
    "unused": "#111111",
}


def diagram(name: str, used_pins: set[int]) -> str:
    width = 420
    height = 790
    left_x = 155
    right_x = 265
    first_y = 115
    row_gap = 31
    radius = 12
    pins = []

    for row in range(20):
        for column in (0, 1):
            pin = row * 2 + column + 1
            x = left_x if column == 0 else right_x
            y = first_y + row * row_gap
            fill = "#d7191c" if pin in used_pins else "#111111"
            label_x = x - 31 if column == 0 else x + 31
            anchor = "end" if column == 0 else "start"
            pins.append(
                f"""
    <circle cx="{x}" cy="{y}" r="{radius}" fill="{fill}"/>
    <text x="{x}" y="{y + 4}" class="pin-number" text-anchor="middle">{pin}</text>
    <text x="{label_x}" y="{y + 5}" class="side-number" text-anchor="{anchor}">{pin}</text>"""
            )

    title = name.capitalize()
    return f"""<?xml version="1.0" encoding="UTF-8"?>
<svg xmlns="http://www.w3.org/2000/svg" width="{width}" height="{height}" viewBox="0 0 {width} {height}" role="img" aria-labelledby="title description">
  <title id="title">{title} Raspberry Pi GPIO pins</title>
  <desc id="description">Raspberry Pi 40-pin header. Pins used by the {name} are red; unused pins are black.</desc>
  <style>
    .title {{ font: 700 24px Arial, sans-serif; fill: #111; }}
    .subtitle {{ font: 14px Arial, sans-serif; fill: #444; }}
    .pin-number {{ font: 700 9px Arial, sans-serif; fill: white; }}
    .side-number {{ font: 12px Arial, sans-serif; fill: #333; }}
    .legend {{ font: 13px Arial, sans-serif; fill: #222; }}
  </style>
  <rect width="{width}" height="{height}" fill="white"/>
  <text x="{width / 2}" y="35" class="title" text-anchor="middle">{title} GPIO usage</text>
  <text x="{width / 2}" y="60" class="subtitle" text-anchor="middle">Raspberry Pi Zero 2W — physical pin numbers</text>
  <rect x="125" y="88" width="170" height="620" rx="14" fill="#ededed" stroke="#777" stroke-width="2"/>
  {"".join(pins)}
  <circle cx="115" cy="745" r="9" fill="#d7191c"/>
  <text x="132" y="750" class="legend">Used by {name}</text>
  <circle cx="265" cy="745" r="9" fill="#111111"/>
  <text x="282" y="750" class="legend">Unused</text>
</svg>
"""


def full_wiring_diagram() -> str:
    width = 520
    height = 835
    left_x = 205
    right_x = 315
    first_y = 115
    row_gap = 31
    radius = 12
    pins = []
    pin_components = {
        pin: [name for name, used_pins in COMPONENTS.items() if pin in used_pins]
        for pin in range(1, 41)
    }

    for row in range(20):
        for column in (0, 1):
            pin = row * 2 + column + 1
            x = left_x if column == 0 else right_x
            y = first_y + row * row_gap
            components = pin_components[pin]

            if len(components) == 2:
                left_color = COLORS[components[0]]
                right_color = COLORS[components[1]]
                fill = f"""
    <path d="M {x} {y - radius} A {radius} {radius} 0 0 0 {x} {y + radius} Z" fill="{left_color}"/>
    <path d="M {x} {y - radius} A {radius} {radius} 0 0 1 {x} {y + radius} Z" fill="{right_color}"/>"""
            else:
                color = COLORS[components[0]] if components else COLORS["unused"]
                fill = f"""
    <circle cx="{x}" cy="{y}" r="{radius}" fill="{color}"/>"""

            label_x = x - 31 if column == 0 else x + 31
            anchor = "end" if column == 0 else "start"
            pins.append(
                f"""{fill}
    <text x="{x}" y="{y + 4}" class="pin-number" text-anchor="middle">{pin}</text>
    <text x="{label_x}" y="{y + 5}" class="side-number" text-anchor="{anchor}">{pin}</text>"""
            )

    legend = [
        ("display", 55, 748),
        ("amplifier", 205, 748),
        ("microphone", 355, 748),
        ("button", 130, 785),
        ("unused", 300, 785),
    ]
    legend_items = "\n".join(
        f"""  <circle cx="{x}" cy="{y}" r="9" fill="{COLORS[name]}"/>
  <text x="{x + 17}" y="{y + 5}" class="legend">{name.capitalize()}</text>"""
        for name, x, y in legend
    )
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

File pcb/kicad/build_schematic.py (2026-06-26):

#!/usr/bin/env python3
"""Generate the PiTalk KiCad schematic from the verified PCB wiring."""

from copy import deepcopy
from pathlib import Path
import uuid

from kiutils.items.common import Effects, Font, Position
from kiutils.items.schitems import (
    Connection,
    GlobalLabel,
    NoConnect,
    SchematicSymbol,
    SymbolProjectInstance,
    SymbolProjectPath,
)
from kiutils.schematic import Schematic
from kiutils.symbol import SymbolLib


HERE = Path(__file__).resolve().parent
OUT = HERE / "pitalk.kicad_sch"
SYMLIB = Path("/Applications/KiCad/KiCad.app/Contents/SharedSupport/symbols")
PROJECT_UUID = str(uuid.uuid4())

COMPONENTS = [
    {
        "ref": "J1",
        "symbol": "Connector_Generic:Conn_02x20_Odd_Even",
        "value": "RPi_Zero2W",
        "footprint": "Connector_PinHeader_2.54mm:PinHeader_2x20_P2.54mm_Vertical",
        "at": (63.5, 85.09),
        "pins": {
            1: "+3V3", 2: "+5V", 3: "TP_SDA", 5: "TP_SCL", 6: "GND",
            7: "TP_INT", 9: "GND", 11: "TP_RST", 12: "I2S_BCLK",
            13: "LCD_RST", 14: "GND", 15: "BTN_SW", 17: "+3V3",
            19: "SPI_MOSI", 20: "GND", 21: "SPI_MISO", 22: "LCD_DC",
            23: "SPI_SCLK", 24: "LCD_CS", 25: "GND", 30: "GND",
            32: "LCD_BL", 33: "BCM13", 34: "GND", 35: "I2S_LRCLK",
            38: "MIC_SD", 39: "GND", 40: "AMP_DIN",
        },
    },
    {
        "ref": "J2",
        "symbol": "Connector_Generic:Conn_01x15",
        "value": "WS_2in_Touch",
        "footprint": "Connector_JST:JST_GH_SM15B-GHS-TB_1x15-1MP_P1.25mm_Horizontal",
        "at": (127.0, 63.5),
        "pins": {
            1: "+3V3", 3: "GND", 4: "SPI_MISO", 5: "SPI_MOSI",
            6: "SPI_SCLK", 8: "LCD_CS", 9: "LCD_DC", 10: "LCD_RST",
            11: "LCD_BL", 12: "TP_SDA", 13: "TP_SCL", 14: "TP_INT",
            15: "TP_RST",
        },
    },
    {
        "ref": "J3",
        "symbol": "Connector_Generic:Conn_01x07",
        "value": "MAX98357A",
        "footprint": "Connector_PinSocket_2.54mm:PinSocket_1x07_P2.54mm_Vertical",
        "at": (127.0, 114.3),
        "pins": {
            1: "I2S_LRCLK", 2: "I2S_BCLK", 3: "AMP_DIN",
            6: "GND", 7: "+5V",
        },
    },
    {
        "ref": "J4",
        "symbol": "Connector_Generic:Conn_01x03",
        "value": "INMP441_A",
        "footprint": "Connector_PinHeader_2.54mm:PinHeader_1x03_P2.54mm_Vertical",
        "at": (127.0, 139.7),
        "pins": {1: "MIC_SD", 2: "+3V3", 3: "GND"},
    },
    {
        "ref": "J5",
        "symbol": "Connector_Generic:Conn_01x03",
        "value": "INMP441_B",
        "footprint": "Connector_PinHeader_2.54mm:PinHeader_1x03_P2.54mm_Vertical",
        "at": (127.0, 154.94),
        "pins": {1: "GND", 2: "I2S_LRCLK", 3: "I2S_BCLK"},
    },
    {
        "ref": "J6",
        "symbol": "Connector_Generic:Conn_01x04",
        "value": "PB_LED",
        "footprint": "Connector_PinHeader_2.54mm:PinHeader_1x04_P2.54mm_Vertical",
        "at": (63.5, 144.78),
        "pins": {1: "BTN_SW", 2: "GND", 3: "LED_A", 4: "GND"},
    },
    {
        "ref": "R1",
        "symbol": "Device:R",
        "value": "330",
        "footprint": "Resistor_THT:R_Axial_DIN0207_L6.3mm_D2.5mm_P10.16mm_Horizontal",
        "at": (91.44, 144.78),
        "pins": {1: "BCM13", 2: "LED_A"},
    },
    {
        "ref": "C1",
        "symbol": "Device:C_Polarized",
        "value": "10uF",
        "footprint": "Capacitor_THT:CP_Radial_D5.0mm_P2.50mm",
        "at": (91.44, 114.3),
        "pins": {1: "+5V", 2: "GND"},
    },
]


def uid() -> str:
    return str(uuid.uuid4())


def load_symbols():
    libraries = {}
    for nickname, filename in (
        ("Connector_Generic", "Connector_Generic.kicad_sym"),
        ("Device", "Device.kicad_sym"),
    ):
        library = SymbolLib.from_file(SYMLIB / filename)
        libraries[nickname] = {symbol.entryName: symbol for symbol in library.symbols}
    return libraries


def pin_definitions(symbol):
    pins = {}
    for unit in symbol.units:
        for pin in unit.pins:
            pins[int(pin.number)] = pin
    return pins


def pin_position(component, pin):
    x, y = component["at"]
    # Symbol-library coordinates use positive Y upward; schematic sheet
    # coordinates use positive Y downward.
    return Position(x + pin.position.X, y - pin.position.Y)


def label_position(position, angle):
    distance = 5.08
    offsets = {
        0: (-distance, 0),
        90: (0, distance),
        180: (distance, 0),
        270: (0, -distance),
    }
    dx, dy = offsets[int(angle or 0) % 360]
    return Position(position.X + dx, position.Y + dy, angle or 0)


def property_copy(properties, key, value, x, y, hidden=False):
    prop = deepcopy(next(prop for prop in properties if prop.key == key))
    prop.value = value
    prop.position = Position(x, y, 0)
    prop.effects = Effects(font=Font(width=1.27, height=1.27), hide=hidden)
    prop.showName = False
    return prop
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

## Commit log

2026-05-28 Add PCB design files
    [pitalk.kicad_sch]
2026-05-28 Add KiCad PCB layout and 3D exports
    [pitalk.kicad_pcb, pitalk.kicad_sch, pitalk_pcb_3d.step]
2026-05-28 Add Blender-rendered KiCad PCB preview
2026-05-28 Fix KiCad PCB render camera
2026-05-28 Fix KiCad PCB render framing
    [pitalk.kicad_pcb, pitalk_pcb_3d.step]
2026-06-06 Move amplifier to external header
    [pitalk.kicad_pcb, pitalk.kicad_sch, pitalk_pcb_3d.step]
2026-06-15 Add pcb2 pin connection doc with verified full wiring table
2026-06-19 Add accessory-pin view, PCB connector subsections, and connector photos
    - Flip Display table to accessory-centric layout with accessory_pin_id
    numbered per the Waveshare 15-pin header
    - Add PCB Connector subsections (Display: JST GH1.25 15p, Amplifier:
    2.54mm 7-pin socket) with reference photos under pcb2/images/
2026-06-20 Expand amplifier/mic pin tables and add component photos
    - Amplifier: list all 7 MAX98357A header pins (add GAIN, SD) with
    accessory_pin_id
    - Microphone: list all 6 INMP441 pins (add L/R) with accessory_pin_id;
    add PCB connector section (two 1x3 male headers) matching the module's
    physical SD/VDD/GND and L/R/WS/SCK left-to-right order
    - Add component/connector photos for display, amplifier, microphone, and
    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
2026-06-20 Add button 1x4 connector, photo, and PCB Board connector summary
    - Button: add PCB connector section (2.54mm 1x4 male header) with photo
    - Add PCB Board section at end summarizing all carrier-board connectors;
    speaker excluded (wires to amplifier output, not the PCB)
2026-06-20 Clarify INMP441 L/R-to-GND tie is made on the PCB, not the mic module
2026-06-20 Rename pcb2 to pcb, replacing the obsolete KiCad design
    [pitalk.kicad_pcb, pitalk.kicad_sch]
2026-06-20 Wire INMP441 L/R channel-select to Pi GND pin 14
    Connect the mic's L/R pin to the Pi's GND on pin 14 through the header
    instead of tying it via the PCB ground pour. Updates the mic pin table,
    note, full-wiring table, and unused-pins list.
2026-06-20 Remove obsolete KiCad generation/render tools
2026-06-26 Add KiCad PCB design artifacts
    [pitalk-B_Cu.gbl, pitalk-B_Mask.gbs, pitalk-B_Silkscreen.gbo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]
2026-06-26 Add PCB design review and reconcile pcb.md docs
    - Add DESIGN_REVIEW.md: independent netlist/ERC/DRC/parity verification report
    - pcb.md: tie all 8 Pi GND pins (add pins 20 & 30 to full-wiring table,
    drop from unused list) to match the schematic/GND plane
    - pcb.md: clarify speaker wires to the amp module's OUT+/OUT- terminals,
    not a carrier PCB connector
    - pcb.md: document MAX98357A onboard defaults (9 dB gain, (L+R)/2 enabled
    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
2026-06-26 Add connector pin labels to PCB silkscreen
    [pitalk.kicad_pcb]
2026-06-26 Re-verify PCB after silkscreen update in DESIGN_REVIEW.md
    Second review pass after the connector-label silkscreen update (3b99e36).
    Confirmed the schematic/netlist are unchanged and all 20 new F.SilkS pin
    labels are correct in name, net, side, and placement. Added Finding #5:
    the regenerated board saves the In1.Cu GND pour unfilled and the committed
    fabrication gerbers are stale (pre-label) — both need a zone fill + fab
    re-export before manufacturing.
2026-06-26 Regenerate PCB fabrication outputs
    [pitalk-B_Cu.gbl, pitalk-B_Mask.gbs, pitalk-B_Silkscreen.gbo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]
2026-06-26 Close Finding #5 in DESIGN_REVIEW.md after fab regeneration
    Third review pass after fabrication regeneration (b4b90ed). Verified the
    regenerated outputs against the current board: In1.Cu gerber carries a
    filled GND plane, the 20 new pin labels are present in F_Silkscreen
    (front-side only), and DRC/statistics are current and clean (76x58,
    61 THT/17 SMD/4 NPTH). Finding #5 resolved; retained a latent caveat that
    a manual GUI re-plot needs Fill All Zones since the saved .kicad_pcb still
    caches the zone unfilled.
